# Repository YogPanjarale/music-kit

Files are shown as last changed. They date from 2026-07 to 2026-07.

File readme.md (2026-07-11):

# Touch Music Kit

Touch Music Kit is an ESP32-based music controller PCB with seven capacitive touch pads, a small OLED display, physical controls, addressable LED output, and a PAM8403 audio amplifier module interface.

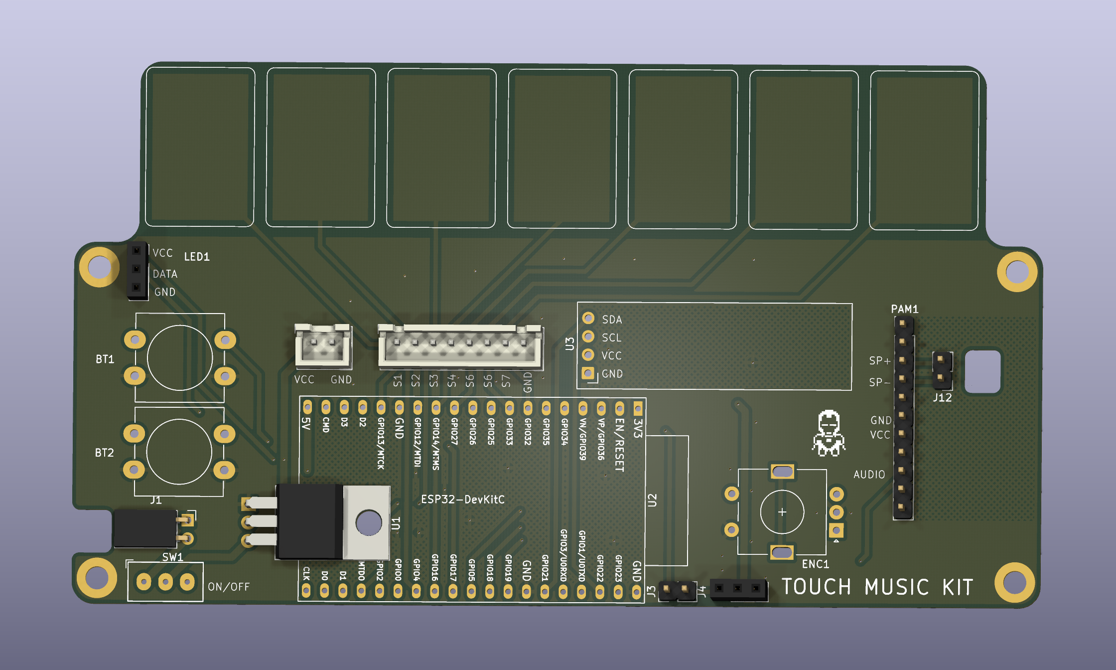
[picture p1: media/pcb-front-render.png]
PCB front render


## Features

- ESP32-DevKitC module as the main controller.
- Seven on-board capacitive touch pads labeled `S1` through `S7`.
- 0.91 inch SSD1306 I2C OLED module.
- Rotary encoder with integrated push switch.
- Two 12 mm push buttons.
- Slide power switch and power input connectors.
- PAM8403 amplifier module header for audio output.
- Speaker output intended for a 0.5 W, 8 ohm, 32 mm speaker through the PAM8403 module.
- NeoPixel-compatible 3-pin LED header.
- LM1117T-3.3 regulator footprint.
- KiCad project files plus fabrication outputs for board manufacturing.

## Repository Layout

```text
.
|-- hardware/
|   `-- touch-kit/
|       |-- music-kit.kicad_pro
|       |-- music-kit.kicad_sch
|       |-- music-kit.kicad_pcb
|       `-- *_production/
|           `-- dated export folder/
|               |-- Gerber ZIP
|               |-- BOM CSV
|               |-- position CSV
|               `-- IPC netlist
|-- media/
|   `-- pcb-front-render.png
`-- software/
```

The `software/` directory is currently empty.

## Hardware Overview

| Designator | Part / Module | Notes |
| --- | --- | --- |
| `U2` | ESP32-DevKitC | Main controller module. |
| `U3` | ER_OLEDM0.91_1x-I2C | 0.91 inch, 128x32, SSD1306 I2C OLED. |
| `ENC1` | EC11-style rotary encoder | Encoder with push switch. |
| `BT1`, `BT2` | 12 mm push buttons | User input buttons. |
| `J5` | JST-XH 1x08 input connector | Breaks out `S1` through `S7` plus `GND`. |
| `LED1` | 3-pin NeoPixel header | `VCC`, `DATA`, `GND`. |
| `PAM1` | PAM8403 module header | 1x11 header with audio output, DAC input, power, and ground nets. |
| `J4` | 3-pin DAC/audio header | `DAC_OUT`, `VCC`, and `GND`; schematic value is `Speakerdf`. |
| `J1`, `J6` | Power connectors | Auxiliary power and JST-XH power input. |
| `SW1` | Slide switch | Board on/off switch. |
| `U1` | LM1117T-3.3 | 3.3 V regulator footprint. |

The board outline is approximately 134 mm x 75 mm, based on the KiCad edge cuts and dimension markings.

## Firmware Pin Map

This map is derived from the KiCad PCB nets connected to `U2` (`ESP32-DevKitC`).

| Signal | ESP32 GPIO | Purpose |
| --- | ---: | --- |
| `S1` | GPIO4 | Capacitive touch input |
| `S2` | GPIO15 | Capacitive touch input |
| `S3` | GPIO13 | Capacitive touch input |
| `S4` | GPIO14 | Capacitive touch input |
| `S5` | GPIO27 | Capacitive touch input |
| `S6` | GPIO33 | Capacitive touch input |
| `S7` | GPIO32 | Capacitive touch input |
| `DAC_MCU` | GPIO25 | ESP32 DAC/audio signal |
| `WS_DATA` | GPIO26 | NeoPixel data |
| `BT1` | GPIO16 | Push button 1 |
| `BT2` | GPIO17 | Push button 2 |
| `ENC_SW` | GPIO5 | Encoder switch |
| `ENC_DT` | GPIO18 | Encoder data |
| `ENC_CLK` | GPIO19 | Encoder clock |
| `SDA` | GPIO21 | OLED I2C data |
| `SCL` | GPIO22 | OLED I2C clock |

Note: the current PCB silkscreen labels the fifth and sixth input positions as `S6`, `S6`. The KiCad nets show those positions as `S5` and `S6`, so verify the board file before ordering or assembling.

## Manufacturing Files

Open the KiCad project from:

```text
hardware/touch-kit/music-kit.kicad_pro
```

Ready-to-send fabrication outputs are under the production export folder in `hardware/touch-kit/`. The current export can be found with:

```text
hardware/touch-kit/*_production/2026-07-02-17-41-01/
```

That folder includes the Gerber ZIP, BOM CSV, position CSV, and IPC netlist generated from the KiCad PCB. If you change the schematic or PCB, regenerate the manufacturing files from KiCad before ordering.

## Assembly Notes

- Confirm `VCC`, `+BATT`, and `GND` with a multimeter before plugging in the ESP32, OLED, or amplifier module.
- Install the ESP32-DevKitC, OLED, PAM8403 module, buttons, encoder, headers, and power connectors according to the silkscreen and BOM.
- Use the PAM8403 module with the knob-style amplifier header expected by `PAM1`.
- Connect the speaker through the PAM8403 module output pins marked `SP+` and `SP-`; do not assume `J4` is the raw speaker output without checking the board file.
- The NeoPixel header `LED1` is labeled `VCC`, `DATA`, `GND`; data is driven by `WS_DATA` / GPIO26.

## Firmware Status

Firmware is not included yet. A firmware project should initialize:

- ESP32 capacitive touch readings for `S1` through `S7`.
- SSD1306 display over I2C on GPIO21/GPIO22.
- Audio or DAC output on GPIO25.
- NeoPixel output on GPIO26.
- Button and encoder inputs on GPIO16, GPIO17, GPIO5, GPIO18, and GPIO19.

## License

This project is licensed under the MIT License. See [LICENSE](LICENSE).

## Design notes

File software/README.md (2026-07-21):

# Touch Music Kit — Firmware

ESP32-DevKitC firmware for the Touch Music Kit PCB. A menu-driven polyphonic
synth: seven pads trigger notes, a rotary encoder drives an OLED menu, and audio
renders to the on-chip DAC (GPIO25) into the PAM8403 amplifier and speaker.

## Build & Flash

Requires [PlatformIO Core](https://platformio.org/install) (`pio`).

```bash
pio run                 # compile
pio run -t upload       # compile + flash over USB
pio device monitor      # serial console @ 115200 baud
pio run -t upload -t monitor   # flash then open the monitor
```

The first `pio run` downloads the ESP32 platform and the three Adafruit
libraries (GFX, SSD1306, NeoPixel), pinned in `platformio.ini`.

## Controls

| Control | GPIO | Action |
| --- | ---: | --- |
| Rotary encoder — rotate | CLK 18 / DT 19 | Move between menu items, or edit the selected value |
| Rotary encoder — press | SW 5 | Toggle **SEL** ⇄ **EDIT** (rotate then edits the value) |
| Button 1 (DOWN) | 16 | Previous scale (jumps the menu to Scale) |
| Button 2 (UP) | 17 | Next scale |
| Pads S1–S7 | see pin map | Play notes in the selected input mode |

Encoder feels backwards? Flip `ENCODER_REVERSE` in `src/main.cpp`.

## Menu

Four items, shown on the 128×32 OLED as `SEL/EDIT  n/4  Label`:

### 1. Input — how a pad triggers a note
- **Capacitive** *(default)* — ESP32 `touchRead()` on the seven pads. This is
  the normal mode for the touch PCB.
- **Digital** — the same seven GPIOs read as active-HIGH digital inputs, for
  comparator / LDR / laser-harp / switch outputs wired into the pad connector.

### 2. Voice — how a note sounds (all rendered to the DAC)
| Voice | Character | Behaviour |
| --- | --- | --- |
| **String** | Plucked, warm | Karplus-Strong; rings out and decays (one-shot) |
| **Piano** | Bright pluck | Shorter pluck + an octave harmonic (one-shot) |
| **Keyboard** | Sustained organ-ish | Sounds while the pad is **held**, releases when let go |
| **Percussion** | Drum hit | Noise burst + pitch-dropping body (one-shot) |
| **Flute** | Breathy, gentle vibrato | Near-pure tone + breath noise; sustains while **held** |

> **Keyboard** and **Flute** sustain while held; the others trigger and decay on
> their own. Note-off is tracked per pad, so releasing a held note fades it out
> cleanly.

### 3. Scale — 7 semitone offsets mapped to the pads
14 scales (Major, Dorian, … Hirajoshi). The two buttons also change this
directly. Root note is C4 (`ROOT` in `src/main.cpp`).

### 4. Screen — OLED orientation
Toggles the OLED between **Normal** and **Flipped** (rotated 180°) so the menu
is readable from the opposite side of the board. Any encoder turn while editing
flips it. Display-only — the LED strip and pad order are not mirrored.

## Sound Reference

### Voices — how each is synthesised

All voices are generated on-chip and played out the DAC; there is no sample
memory. Each pad = one note of the current scale.

| Voice | Technique | Character & tips |
| --- | --- | --- |
| **String** | Karplus-Strong: a burst of noise cycled through a short delay line that low-pass filters itself each pass, so it starts bright and mellows as it rings. | Warm plucked-string / harp. Long natural decay (~3 s). Best with pentatonic/blues scales for a harp feel. |
| **Piano** | Same pluck, but shorter and less smoothed, plus an octave-up copy layered on top. | Brighter, more percussive attack, shorter tail. Good for melodic lines and chords. |
| **Keyboard** | Additive oscillator: fundamental + octave + fifth-above sines summed, shaped by an attack/release envelope. | Sustained organ-ish tone that **holds while a pad is held**. Fuller, more "electric organ" than the plucks. |
| **Percussion** | A short pitched sine "body" whose pitch drops instantly, mixed with a fast-decaying noise burst. | Drum/tom-like hits. Lower pads sound like toms/kick, higher pads snappier. Scale mostly changes the pitch of the thump. |
| **Flute** | Near-pure sine (fundamental + a faint octave) plus a little breath noise, with a gentle ~5 Hz vibrato, attack/release envelope. | Soft, airy, **sustains while held**. Slow attack makes fast passages blur — good for slow melodies. |

Plucks (String, Piano) and Percussion are *one-shot*: they trigger and ring out
on their own. Keyboard and Flute are *sustained*: they keep sounding until you
release the pad. Up to 10 notes can sound at once (`MAX_VOICES`).

### Scales — the mood of each

A scale is just seven semitone offsets from the root (C4) mapped to pads S1→S7,
low to high. Switch scales with the encoder (Scale item) or the two buttons.
Rough character of each:

**Common modes**
- **Major (Ionian)** — the standard "happy"/bright do-re-mi scale.
- **Natural Minor (Aeolian)** — the standard "sad"/serious minor scale.
- **Dorian** — minor but hopeful; jazzy, Celtic, folk flavour.
- **Phrygian** — dark minor with a lowered 2nd; Spanish/flamenco, metal edge.
- **Lydian** — major with a raised 4th; dreamy, floating, "film score" wonder.
- **Mixolydian** — major with a lowered 7th; bluesy, rock, dominant feel.
- **Locrian** — the darkest, most unstable mode; tense and dissonant.

**Colourful / exotic**
- **Harmonic Minor** — minor with a raised 7th; dramatic, classical, Middle-Eastern.
- **Phrygian Dominant** — Spanish/Arabic sound; the "flamenco" scale.
- **Hirajoshi** — a Japanese pentatonic scale; sparse, meditative, koto-like.
- **Whole Tone** — every step a whole tone apart; dreamlike, ambiguous, "no home".

**Easy / forgiving (great for improvising — no wrong notes)**
- **Major Pentatonic** — five bright notes; cheerful, folky, hard to sound bad.
- **Minor Pentatonic** — five moody notes; the backbone of rock/blues solos.
- **Blues** — minor pentatonic plus the "blue note"; soulful, gritty.

If you just want to noodle and have it always sound musical, pick one of the
pentatonic scales or Blues.

## Pin Map

Matches the PCB net map (`../readme.md`).

| Signal | GPIO | Notes |
| --- | ---: | --- |
| Pad S1 | 4 | touch T0 |
| Pad S2 | 15 | touch T3 |
| Pad S3 | 13 | touch T4 |
| Pad S4 | 14 | touch T6 |
| Pad S5 | 27 | touch T7 |
| Pad S6 | 33 | touch T8 |
| Pad S7 | 32 | touch T9 |
| DAC audio out | 25 | → PAM8403 → speaker |
| NeoPixel data | 26 | `WS_DATA`, one LED per pad |
| Button 1 / 2 | 16 / 17 | active-LOW, internal pull-ups |
| Encoder SW / CLK / DT | 5 / 18 / 19 | active-LOW switch, pull-ups |
| OLED SDA / SCL | 21 / 22 | SSD1306 @ I2C 0x3C |

## Tuning

Everything is `const` at the top of `src/main.cpp`:

- **Touch sensitivity** — `TOUCH_ON` / `TOUCH_OFF` (hysteresis; lower = touched).
  Check the "resting touch levels" line printed at boot and set `TOUCH_ON` well
  below the resting value.
- **Digital input polarity** — `DIGITAL_INPUT_ACTIVE_LOW`, `DIGITAL_INPUT_PULLDOWNS`.
- **Retrigger rate** — `COOLDOWN_MS` (min gap between triggers on one pad).
- **Voice character** — the `INSTRUMENTS[]` table: pluck `decay`/`smoothPasses`/
  `lifeSec`, Keyboard/Flute `attackSec`/`releaseSec`, Percussion `percDecaySec`.
  The Keyboard and Flute harmonic/breath mix lives in `renderSample()`
  (`VK_TONE` / `VK_FLUTE` branches); flute vibrato is `VIB_RATE`/`VIB_DEPTH`.
- **Polyphony / audio** — `MAX_VOICES`, `SR` (sample rate), `LED_BRIGHTNESS`.

Serial (115200) prints every trigger with pad, frequency, and (in Capacitive
mode) the raw touch value — useful for calibrating `TOUCH_ON`/`TOUCH_OFF`.

## Layout

```
software/
├── platformio.ini   # esp32dev / Arduino env + pinned libs
├── src/main.cpp      # firmware
├── old.cpp           # previous single-mode sketch, kept for reference (not built)
└── README.md
```

`old.cpp` sits outside `src/`, so PlatformIO does not compile it.

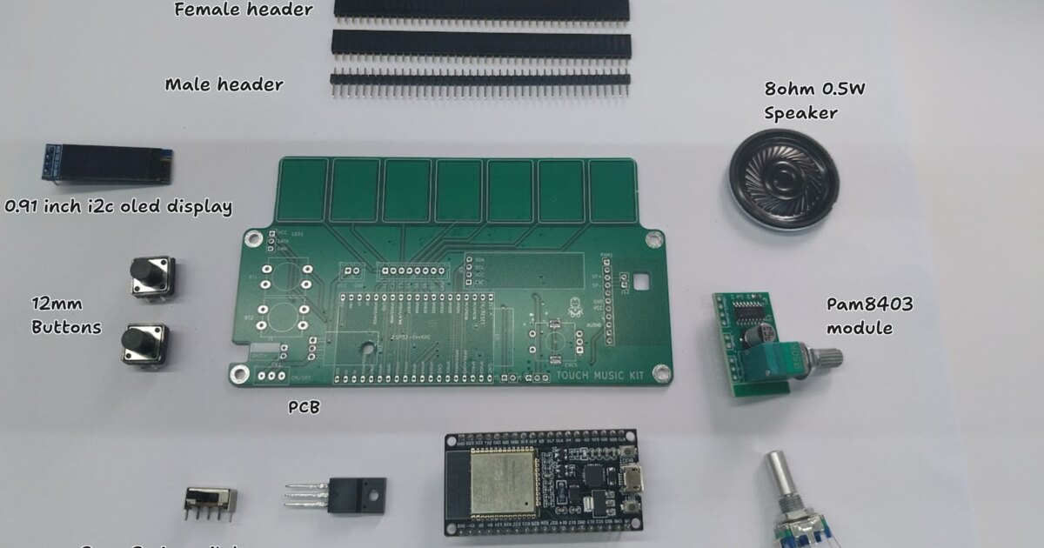
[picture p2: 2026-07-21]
docs/cover.jpg

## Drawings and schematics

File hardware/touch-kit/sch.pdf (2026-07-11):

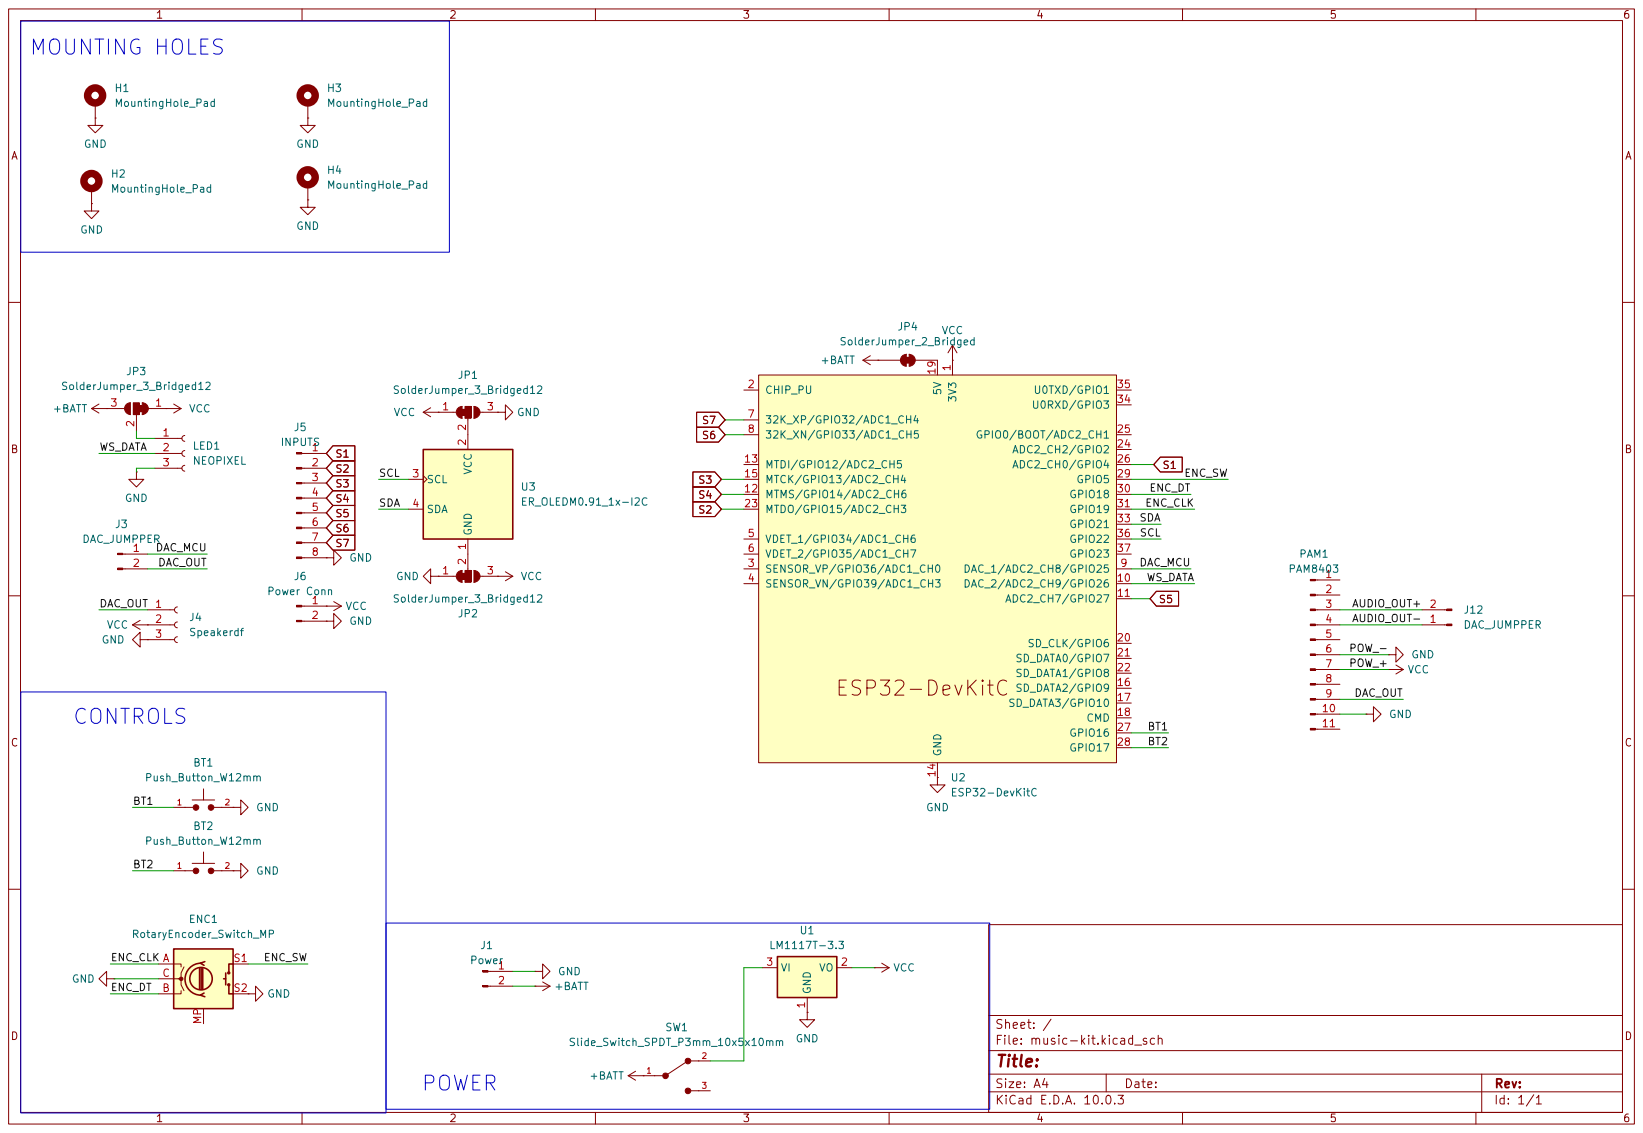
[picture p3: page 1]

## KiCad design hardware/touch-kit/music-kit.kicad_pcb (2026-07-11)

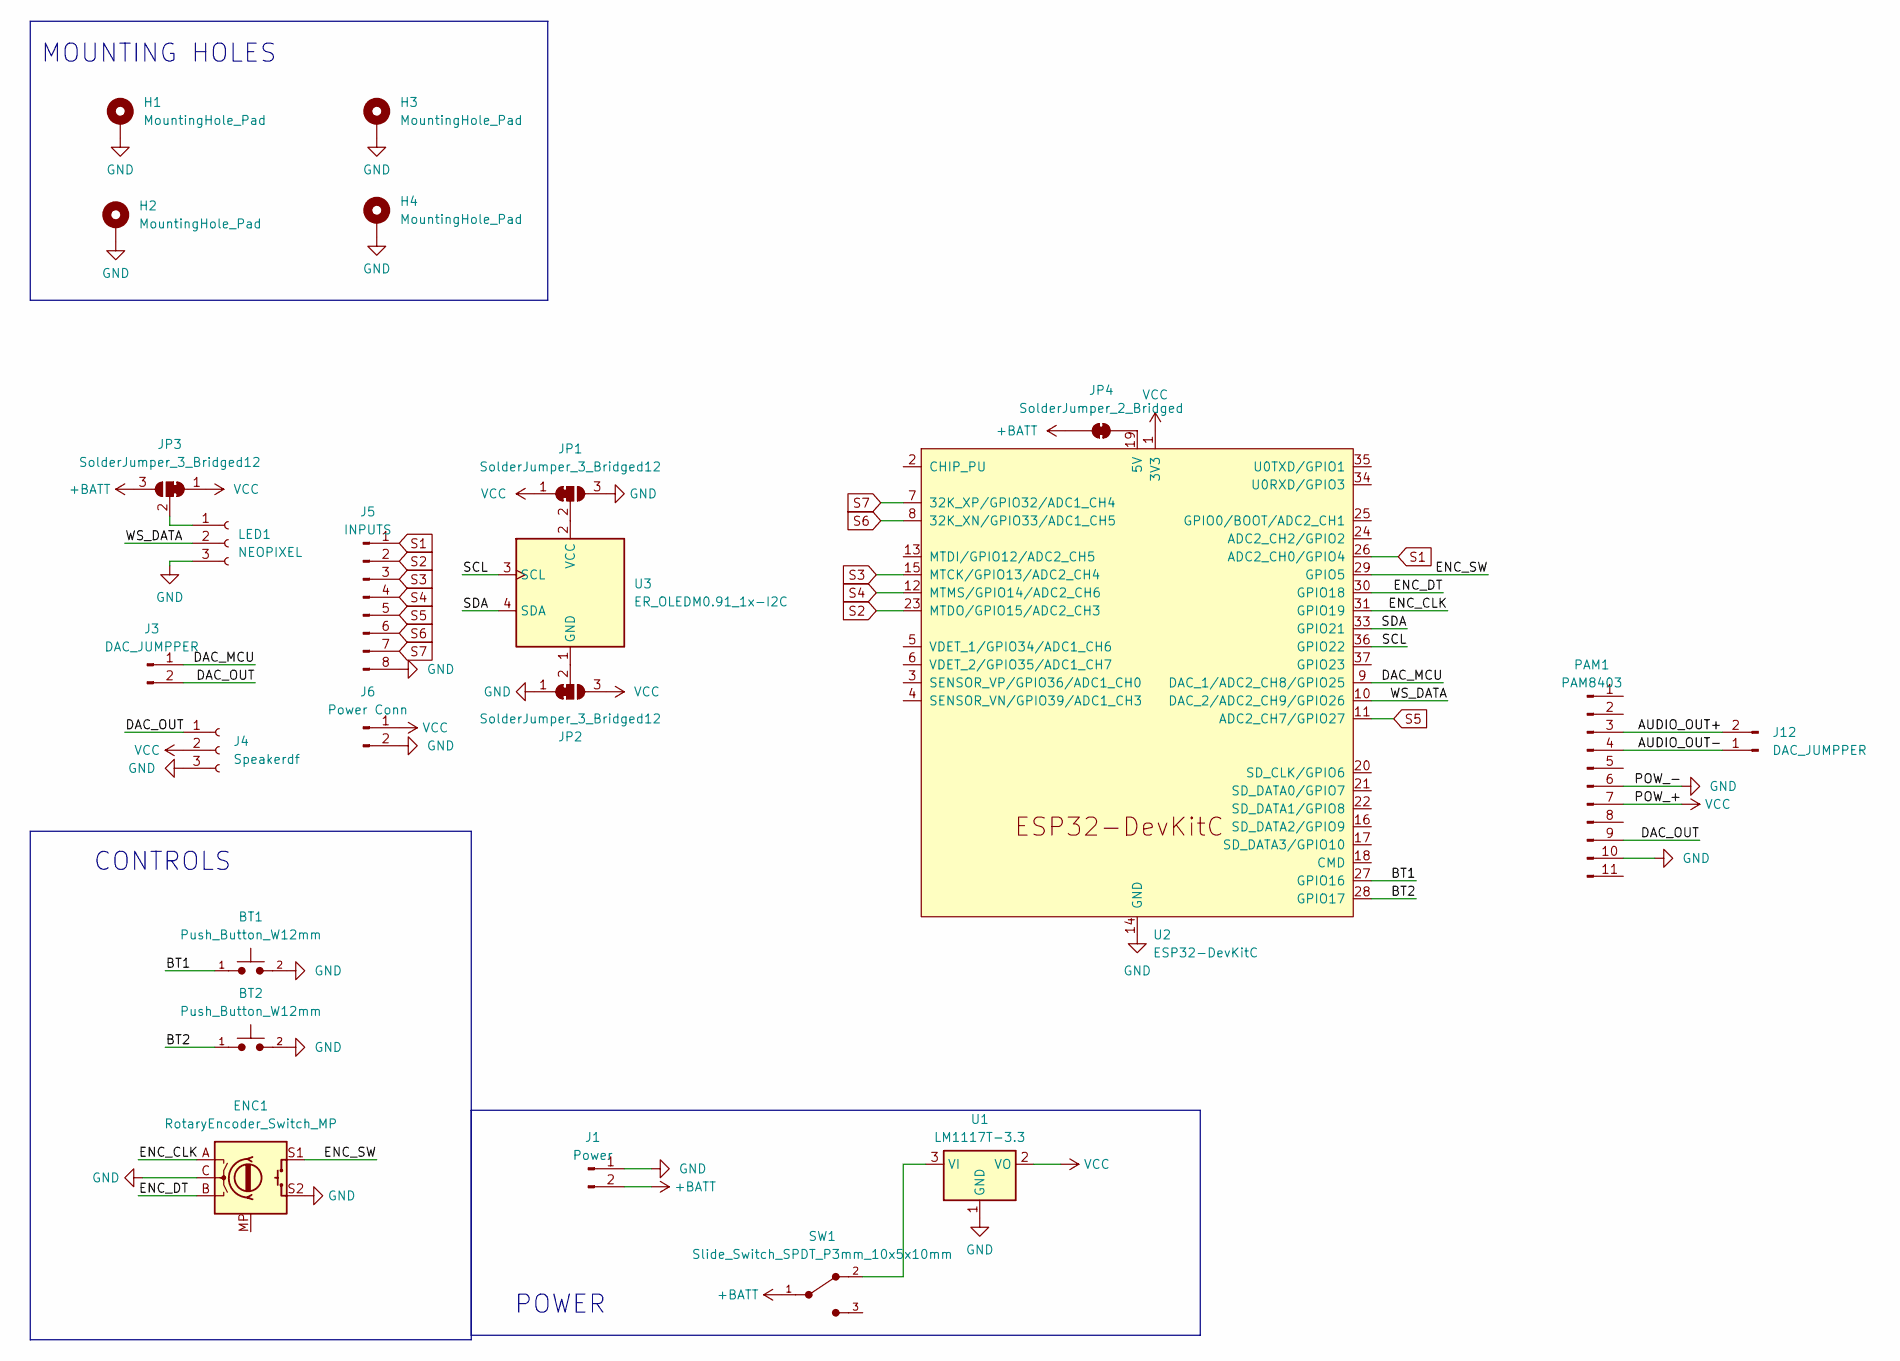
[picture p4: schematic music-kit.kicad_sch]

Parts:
BT1, BT2: Push_Button_W12mm
ENC1: RotaryEncoder_Switch_MP; RotaryEncoder_Alps_EC11E-Switch_Vertical_H20mm
H1, H2, H3, H4: MountingHole_Pad; MountingHole_3.2mm_M3_DIN965_Pad
J1: Power; PinSocket_1x02_P2.54mm_Horizontal
J3, J12: DAC_JUMPPER; PinHeader_1x02_P2.54mm_Vertical
J4: Speakerdf; PinSocket_1x03_P2.54mm_Vertical
J5: INPUTS; JST_XH_B8B-XH-A_1x08_P2.50mm_Vertical
J6: Power Conn; JST_XH_B2B-XH-A_1x02_P2.50mm_Vertical
JP1, JP2, JP3: SolderJumper_3_Bridged12; SolderJumper-3_P1.3mm_Bridged12_Pad1.0x1.5mm
JP4: SolderJumper_2_Bridged; SolderJumper-2_P1.3mm_Bridged_Pad1.0x1.5mm
LED1: NEOPIXEL; PinSocket_1x03_P2.54mm_Vertical
PAM1: PAM8403; PinHeader_1x11_P2.54mm_Vertical
SW1: Slide_Switch_SPDT_P3mm_10x5x10mm
U1: LM1117T-3.3; TO-220-3_Horizontal_TabDown
U2: ESP32-DevKitC
U3: ER_OLEDM0.91_1x-I2C

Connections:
+BATT: J1.2, JP3.3 (B), JP4.1 (A), SW1.1
/AUDIO_OUT+: J12.2, PAM1.3
/AUDIO_OUT-: J12.1, PAM1.4
/BT1: BT1.1, U2.27 (GPIO16)
/BT2: BT2.1, U2.28 (GPIO17)
/DAC_MCU: J3.1, U2.9 (DAC_1/ADC2_CH8/GPIO25)
/DAC_OUT: J3.2, J4.1, PAM1.9
/ENC_CLK: ENC1.A, U2.31 (GPIO19)
/ENC_DT: ENC1.B, U2.30 (GPIO18)
/ENC_SW: ENC1.S1, U2.29 (GPIO5)
/SCL: U2.36 (GPIO22), U3.3 (SCL)
/SDA: U2.33 (GPIO21), U3.4 (SDA)
/WS_DATA: LED1.2, U2.10 (DAC_2/ADC2_CH9/GPIO26)
GND: BT1.2, BT2.2, ENC1.C, ENC1.S2, H1.1 (1_1), H2.1 (1_1), H3.1 (1_1), H4.1 (1_1), J1.1, J4.3, J5.8, J6.2, JP1.3 (B), JP2.1 (A), LED1.3, PAM1.6, PAM1.10, U1.1 (GND), U2.14 (GND), U2.32 (GND), U2.38 (GND)
unnamed: JP1.2 (C), U3.2 (VCC)
unnamed: JP2.2 (C), U3.1 (GND)
unnamed: JP3.2 (C), LED1.1
unnamed: JP4.2 (B), U2.19 (5V)
unnamed: SW1.2, U1.3 (VI)
S1: J5.1, U2.26 (ADC2_CH0/GPIO4)
S2: J5.2, U2.23 (MTDO/GPIO15/ADC2_CH3)
S3: J5.3, U2.15 (MTCK/GPIO13/ADC2_CH4)
S4: J5.4, U2.12 (MTMS/GPIO14/ADC2_CH6)
S5: J5.5, U2.11 (ADC2_CH7/GPIO27)
S6: J5.6, U2.8 (32K_XN/GPIO33/ADC1_CH5)
S7: J5.7, U2.7 (32K_XP/GPIO32/ADC1_CH4)
VCC: J4.2, J6.1, JP1.1 (A), JP2.3 (B), JP3.1 (A), PAM1.7, U1.2 (VO), U2.1 (3V3)

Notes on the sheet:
POWER
CONTROLS
MOUNTING HOLES

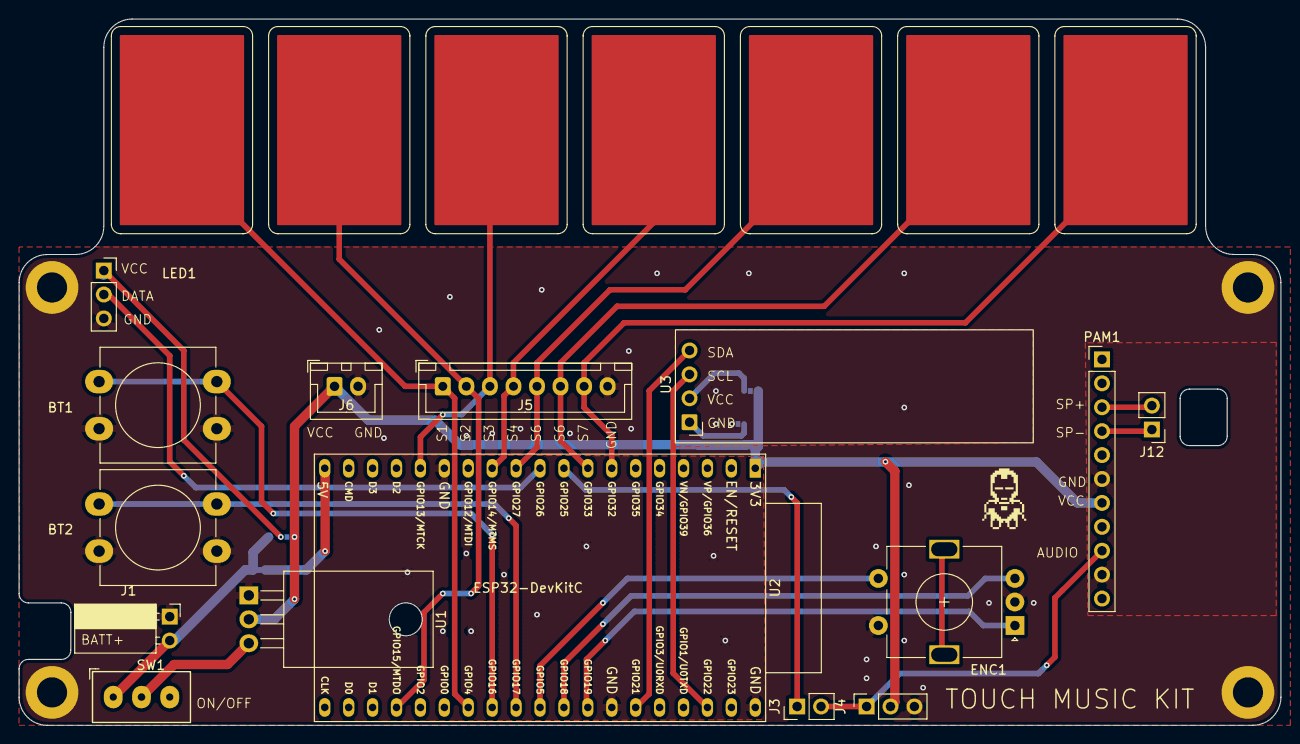
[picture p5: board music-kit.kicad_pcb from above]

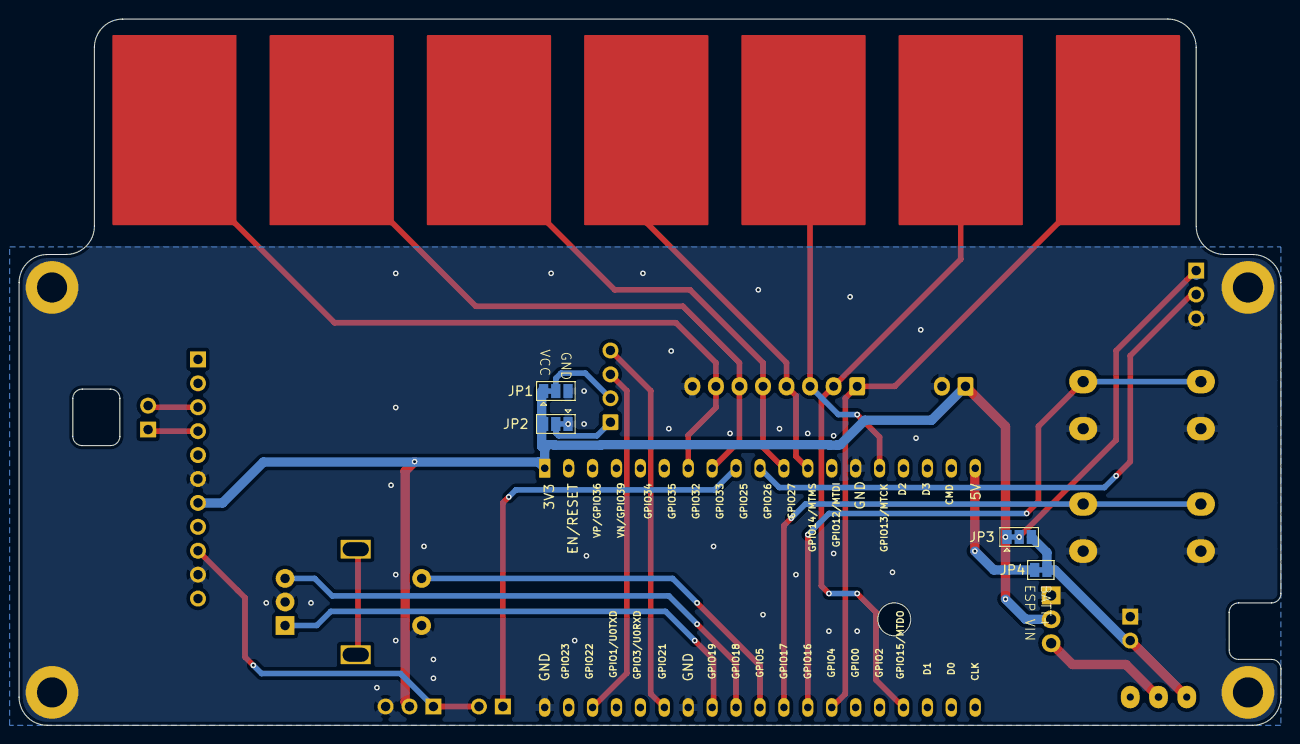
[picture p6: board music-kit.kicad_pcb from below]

Board: 2 copper layers, 134.0 x 75.0 mm, 23 parts (4 on the bottom side), 27 nets.

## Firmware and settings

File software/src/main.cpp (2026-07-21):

/*
 * Touch Music Kit  ->  Menu-driven synth
 * ------------------------------------------------------------
 * INPUT MODES (how a pad triggers a note):
 *   - Capacitive : ESP32 touchRead() on the 7 pads (default; matches the PCB).
 *   - Digital    : same 7 GPIOs read as active-HIGH digital inputs
 *                  (comparator / LDR / laser-harp / switch outputs).
 *
 * INSTRUMENT TYPES (how a note sounds, all rendered to the DAC):
 *   - String     : plucked Karplus-Strong, rings out and decays.
 *   - Piano      : short, bright plucked variant with an octave harmonic.
 *   - Keyboard   : sustained organ-ish tone; holds while the pad is held,
 *                  releases when let go (only Capacitive/Digital press-hold).
 *   - Percussion : drum-style noise+pitch hit, one-shot.
 *
 * Rotary encoder menu:  GPIO5 = SW   GPIO18 = CLK   GPIO19 = DT
 * Scale buttons:        GPIO16 = DOWN (prev)   GPIO17 = UP (next)
 *   Wire each button between the pin and GND (internal pull-ups are used).
 *
 * Audio renders in small chunks in loop() between scans, so notes ring out
 * continuously without blocking input.
 *
 * Board: ESP32-DevKitC. DAC = GPIO25 -> PAM8403 -> speaker. Serial @ 115200.
 */

#include <Arduino.h>
#include <Wire.h>
#include <Adafruit_GFX.h>
#include <Adafruit_SSD1306.h>
#include <Adafruit_NeoPixel.h>
#include <math.h>
#include <string.h>

// ============================================================
//  CONFIG
// ============================================================
const int DAC_PIN = 25;

const int NUM = 7;
// Pad order follows the PCB net map S1..S7 (see readme "Firmware Pin Map").
const uint8_t PAD_PIN[NUM] = {
    4,   // S1: GPIO4  / touch T0
    15,  // S2: GPIO15 / touch T3
    13,  // S3: GPIO13 / touch T4
    14,  // S4: GPIO14 / touch T6
    27,  // S5: GPIO27 / touch T7
    33,  // S6: GPIO33 / touch T8
    32   // S7: GPIO32 / touch T9
};

// Capacitive touch detection with hysteresis: touchRead returns LOWER when touched.
const int TOUCH_ON   = 30;   // below this = touched
const int TOUCH_OFF  = 45;   // above this = released
const uint32_t COOLDOWN_MS = 120;   // min time between triggers on the same pad

// Digital input mode: same 7 GPIOs, active-HIGH by default.
const bool DIGITAL_INPUT_PULLDOWNS  = true;
const bool DIGITAL_INPUT_ACTIVE_LOW = false;
uint8_t    lastDigitalActiveMask    = 0xFF; // force one raw GPIO status print at boot

enum PlayMode {
  MODE_CAPACITIVE = 0,   // ESP32 touchRead pads
  MODE_DIGITAL,          // active-HIGH GPIO inputs (comparator / LDR / switch)
  PLAY_MODE_COUNT
};
PlayMode playMode = MODE_CAPACITIVE;

// Scale-select buttons (active LOW, internal pull-up)
const int BTN_PIN[2] = { 16, 17 };   // [0] = DOWN/prev, [1] = UP/next

// Rotary encoder (active LOW switch, internal pull-ups)
const int ENC_SW_PIN  = 5;
const int ENC_CLK_PIN = 18;
const int ENC_DT_PIN  = 19;
const bool ENCODER_REVERSE = false;  // flip if clockwise feels backwards

// 0.91" OLED (SSD1306, 128x32) on I2C: SDA=21, SCL=22, address 0x3C
const int OLED_SDA  = 21;
const int OLED_SCL  = 22;
const int OLED_ADDR = 0x3C;
Adafruit_SSD1306 display(128, 32, &Wire, -1);
bool oledOK = false;

// NeoPixel pin-activity display: one RGB LED per pad on GPIO26 (PCB WS_DATA net).
// LED index matches pad index; active pads stay lit, triggers flash briefly.
const int LED_PIN   = 26;
const int LED_COUNT = NUM;
Adafruit_NeoPixel strip(LED_COUNT, LED_PIN, NEO_GRB + NEO_KHZ800);
const uint8_t LED_BRIGHTNESS = 70; // global cap (keeps current draw sane)
const uint8_t CAP_ACTIVE_RGB[3] = {   0, 220, 255 }; // capacitive touch active
const uint8_t DIG_ACTIVE_RGB[3] = { 255,  40,   0 }; // digital GPIO active

// LED signal state: active pads stay lit, fresh triggers fade from white.
float    ledLevel[NUM] = { 0 };
bool     ledsDirty     = true;     // forces one redraw after state changes
uint32_t lastFrame     = 0;
const uint32_t FRAME_MS = 33;      // ~30fps, only redraws on changes/flash decay

// ============================================================
//  SCALES  (root + 7 semitone offsets)
// ============================================================
const float ROOT = 261.63f;          // C4 -- change to transpose everything

// 7 semitone steps per scale, relative to ROOT.
// Add a row here and matching names below -- NUM_SCALES updates itself.
const int SCALE_STEPS[][NUM] = {
  {  0,  2,  4,  5,  7,  9, 11 },   // Major (Ionian)
  {  0,  2,  3,  5,  7,  9, 10 },   // Dorian
  {  0,  1,  3,  5,  7,  8, 10 },   // Phrygian
  {  0,  2,  4,  6,  7,  9, 11 },   // Lydian
  {  0,  2,  4,  5,  7,  9, 10 },   // Mixolydian
  {  0,  2,  3,  5,  7,  8, 10 },   // Natural Minor (Aeolian)
  {  0,  1,  3,  5,  6,  8, 10 },   // Locrian
  {  0,  2,  3,  5,  7,  8, 11 },   // Harmonic Minor
  {  0,  2,  4,  7,  9, 12, 14 },   // Major Pentatonic (runs into next octave)
  {  0,  3,  5,  7, 10, 12, 15 },   // Minor Pentatonic (runs into next octave)
  {  0,  3,  5,  6,  7, 10, 12 },   // Blues
  {  0,  2,  4,  6,  8, 10, 12 },   // Whole Tone
  {  0,  1,  4,  5,  7,  8, 10 },   // Phrygian Dominant (Spanish/Arabic)
  {  0,  2,  3,  7,  8, 12, 14 },   // Hirajoshi (Japanese)
};
const char* SCALE_NAME[] = {
  "Major", "Dorian", "Phrygian", "Lydian", "Mixolydian", "Natural Minor",
  "Locrian", "Harmonic Minor", "Major Pentatonic", "Minor Pentatonic",
  "Blues", "Whole Tone", "Phrygian Dominant", "Hirajoshi"
};
const char* SCALE_SHORT_NAME[] = {
  "Major", "Dorian", "Phryg", "Lydian", "Mixolyd", "NatMin",
  "Locrian", "HarmMin", "MajPent", "MinPent", "Blues", "Whole",
  "PhrDom", "Hirajo"
};
const int NUM_SCALES = sizeof(SCALE_STEPS) / sizeof(SCALE_STEPS[0]);

// ============================================================
//  INSTRUMENTS  (voice families)
// ============================================================
enum VoiceKind {
  VK_PLUCK,   // Karplus-Strong pluck (self-decaying)
  VK_TONE,    // sustained additive oscillator with attack/release envelope
  VK_PERC,    // percussive noise + pitched body, one-shot
  VK_FLUTE    // sustained breathy near-sine tone with gentle vibrato
};

// Sustained voices hold while the pad is held and fade on release.
inline bool isSustainedKind(VoiceKind k) { return k == VK_TONE || k == VK_FLUTE; }

struct Instrument {
  const char* name;
  const char* detail;
  VoiceKind   kind;
  // --- pluck params ---
  float decay;
  int   smoothPasses;
  float lifeSec;
  bool  harmonic;      // add an octave-up pluck
  // --- tone params ---
  float attackSec;
  float releaseSec;
  // --- perc params ---
  float percDecaySec;
};

const Instrument INSTRUMENTS[] = {
  // name          detail          kind      decay    sm  life   harm    atk     rel    perc
  { "String",     "Plucked",      VK_PLUCK, 0.9968f, 5,  3.2f,  false,  0.0f,   0.0f,  0.0f  },
  { "Piano",      "Bright pluck", VK_PLUCK, 0.9928f, 1,  1.4f,  true,   0.0f,   0.0f,  0.0f  },
  { "Keyboard",   "Sustained",    VK_TONE,  0.0f,    0,  0.0f,  false,  0.006f, 0.18f, 0.0f  },
  { "Percussion", "Drum hits",    VK_PERC,  0.0f,    0,  0.0f,  false,  0.0f,   0.0f,  0.32f },
  { "Flute",      "Breathy",      VK_FLUTE, 0.0f,    0,  0.0f,  false,  0.040f, 0.12f, 0.0f  },
};
const int NUM_INSTRUMENTS = sizeof(INSTRUMENTS) / sizeof(INSTRUMENTS[0]);

int   scaleIdx      = 0;
int   instrumentIdx = 0;
float noteFreq[NUM];                 // current pad frequencies (built from scale)

enum MenuItem {
  MENU_MODE = 0,
  MENU_INSTRUMENT,
  MENU_SCALE,
  MENU_SCREEN,
  MENU_COUNT
};

int  menuIdx     = MENU_MODE;
bool menuEditing = false;
bool screenFlipped = false;   // true = OLED rotated 180 for viewing from the far side
const char* scaleButtonMsg = "";
uint32_t scaleButtonMsgUntil = 0;

// ---- forward declarations ----
void drawMenu();
void configurePadInputs();
void resetPadStates();
void startPluck(float freq, float decay, int smoothPasses, float lifeSec);

int wrapIndex(int value, int count) {
  while (value < 0) value += count;
  while (value >= count) value -= count;
  return value;
}

void pulseAllLeds(float level = 220.0f) {
  for (int i = 0; i < NUM; i++) ledLevel[i] = level;
  ledsDirty = true;
}

void applyScale() {
  for (int i = 0; i < NUM; i++) {
    noteFreq[i] = ROOT * powf(2.0f, SCALE_STEPS[scaleIdx][i] / 12.0f);
  }
  Serial.printf("scale -> %s\n", SCALE_NAME[scaleIdx]);
  pulseAllLeds();
  drawMenu();
}

void changeScale(int delta) {
  if (delta == 0) return;
  scaleIdx = wrapIndex(scaleIdx + delta, NUM_SCALES);
  applyScale();
}

void changeInstrument(int delta) {
  if (delta == 0) return;
  instrumentIdx = wrapIndex(instrumentIdx + delta, NUM_INSTRUMENTS);
  Serial.printf("voice -> %s\n", INSTRUMENTS[instrumentIdx].name);
  pulseAllLeds();
  drawMenu();
}

const char* playModeName() {
  return playMode == MODE_CAPACITIVE ? "Capacitive" : "Digital";
}

void setPlayMode(PlayMode mode) {
  if (playMode == mode) return;
  playMode = mode;
  configurePadInputs();
  resetPadStates();
  Serial.printf("mode -> %s\n", playModeName());
  drawMenu();
}

void changePlayMode(int delta) {
  if (delta == 0) return;
  setPlayMode((PlayMode)wrapIndex((int)playMode + delta, PLAY_MODE_COUNT));
}

void applyScreenRotation() {
  if (!oledOK) return;
  display.setRotation(screenFlipped ? 2 : 0);   // SSD1306: 2 = 180 degrees
}

void toggleScreenFlip() {
  screenFlipped = !screenFlipped;
  applyScreenRotation();
  Serial.printf("screen -> %s\n", screenFlipped ? "flipped 180" : "normal");
  drawMenu();
}

// ============================================================
//  OLED MENU
// ============================================================
const int OLED_W = 128;
const int OLED_CHAR_COLS = 21;       // 128px / 6px font width at text size 1

void printClipped(const char* text, int maxChars = OLED_CHAR_COLS) {
  for (int i = 0; i < maxChars && text[i] != '\0'; i++) {
    display.write(text[i]);
  }
}

const char* menuLabel() {
  switch (menuIdx) {
    case MENU_MODE:       return "Input";
    case MENU_INSTRUMENT: return "Voice";
    case MENU_SCALE:      return "Scale";
    case MENU_SCREEN:     return "Screen";
    default:              return "Menu";
  }
}

const char* menuValue() {
  switch (menuIdx) {
    case MENU_MODE:       return playModeName();
    case MENU_INSTRUMENT: return INSTRUMENTS[instrumentIdx].name;
    case MENU_SCALE:      return SCALE_SHORT_NAME[scaleIdx];
    case MENU_SCREEN:     return screenFlipped ? "Flipped" : "Normal";
    default:              return "";
  }
}

const char* menuDetail() {
  switch (menuIdx) {
    case MENU_MODE:
      return playMode == MODE_CAPACITIVE ? "Touch pads" : "GPIO inputs";
    case MENU_INSTRUMENT:
      return INSTRUMENTS[instrumentIdx].detail;
    case MENU_SCALE:
      return scaleButtonMsgUntil ? scaleButtonMsg : SCALE_NAME[scaleIdx];
    case MENU_SCREEN:
      return screenFlipped ? "180 view" : "Upright";
    default:
      return "";
  }
}

void drawCenteredText(const char* text, int y, uint8_t size) {
  int16_t x1, y1;
  uint16_t w, h;
  display.setTextSize(size);
  display.getTextBounds(text, 0, y, &x1, &y1, &w, &h);
  int x = (OLED_W - (int)w) / 2 - x1;
  if (x < 0) x = 0;
  display.setCursor(x, y);
  display.print(text);
}

void drawMenuHeader() {
  char header[24];
  snprintf(header, sizeof(header), "%s %d/%d %s", menuEditing ? "EDIT" : "SEL", menuIdx + 1, MENU_COUNT, menuLabel());

  display.setTextSize(1);
  if (menuEditing) {
    display.fillRect(0, 0, OLED_W, 9, SSD1306_WHITE);
    display.setTextColor(SSD1306_BLACK);
  } else {
    display.setTextColor(SSD1306_WHITE);
  }
  display.setCursor(0, 0);
  printClipped(header);
  display.setTextColor(SSD1306_WHITE);
}

void drawMenu() {
  if (!oledOK) return;

  display.clearDisplay();
  drawMenuHeader();
  drawCenteredText(menuValue(), 11, 2);
  drawCenteredText(menuDetail(), 25, 1);
  display.display();
}

// ============================================================
//  SYNTH ENGINE  (polyphonic, multi-family)
// ============================================================
const int     SR         = 20000;
const int     MAX_LEN    = 600;
const int     MAX_VOICES = 10;
const uint8_t DC_MID     = 128;

// Sine lookup table (power-of-two length for cheap phase masking).
const int   SINE_N = 256;
float       sineTab[SINE_N];

inline float sineLookup(float cycles) {
  // cycles >= 0; masking handles values >= 1.0 (harmonics).
  int idx = (int)(cycles * SINE_N) & (SINE_N - 1);
  return sineTab[idx];
}

// Shared low-frequency oscillator for flute vibrato.
const float VIB_RATE  = 5.0f;          // Hz
const float VIB_DEPTH = 0.004f;        // +/- pitch modulation (~7 cents)
const float VIB_INC   = VIB_RATE / SR;
float       vibratoPhase = 0.0f;

// Fast noise for percussion (xorshift; avoids per-sample random()).
uint32_t rngState = 0x9E3779B9u;
inline float fastNoise() {
  rngState ^= rngState << 13;
  rngState ^= rngState >> 17;
  rngState ^= rngState << 5;
  return (int32_t)rngState * (1.0f / 2147483648.0f);  // ~ -1..1
}

struct Voice {
  bool      active;
  VoiceKind kind;
  int       pad;        // owning pad for sustained note-off, -1 if none
  // Karplus buffer (pluck)
  float     buf[MAX_LEN];
  int       len, idx;
  float     decay;
  uint32_t  life;
  // Oscillator (tone / perc)
  float     phase;      // cycles [0,1)
  float     phaseInc;   // cycles per sample
  float     env;        // amplitude envelope
  float     env2;       // perc noise-transient envelope
  bool      sustaining; // tone: pad still held
  float     attackRate, releaseRate;
};
Voice voices[MAX_VOICES];
int   nextVoice = 0;
int   padVoice[NUM];    // sustained voice index per pad, -1 = none

void smoothBuffer(float *b, int len, int passes) {
  for (int p = 0; p < passes; p++) {
    float prev = b[len - 1];
    for (int i = 0; i < len; i++) {
      float cur = b[i];
      int n = i + 1;
      if (n >= len) n = 0;
      float nv = (prev + 2.0f * cur + b[n]) * 0.25f;
      prev = cur;
      b[i] = nv;
    }
  }
}

// Pick a free voice, or steal the round-robin one. Clears any pad ownership.
int allocVoice() {
  int v = -1;
  for (int i = 0; i < MAX_VOICES; i++) {
    if (!voices[i].active) { v = i; break; }
  }
  if (v < 0) {
    v = nextVoice;
    nextVoice = (nextVoice + 1) % MAX_VOICES;
  }
  Voice &vc = voices[v];
  if (vc.pad >= 0 && vc.pad < NUM && padVoice[vc.pad] == v) padVoice[vc.pad] = -1;
  vc.pad = -1;
  return v;
}

void startPluck(float freq, float decay = 0.9968f, int smoothPasses = 5, float lifeSec = 3.2f) {
  if (freq <= 0) return;
  int v = allocVoice();
  Voice &vc = voices[v];
  vc.kind = VK_PLUCK;
  vc.len = SR / freq;
  if (vc.len > MAX_LEN) vc.len = MAX_LEN;
  if (vc.len < 2) vc.len = 2;
  for (int i = 0; i < vc.len; i++) {
    vc.buf[i] = (random(0, 2001) / 1000.0f) - 1.0f;
  }
  smoothBuffer(vc.buf, vc.len, smoothPasses);
  vc.idx = 0;
  vc.decay = decay;
  vc.life = (uint32_t)(SR * lifeSec);
  vc.active = true;
}

// Start a sustained voice (Keyboard tone or Flute) owned by a pad.
void startTone(VoiceKind kind, float freq, float attackSec, float releaseSec, int pad) {
  if (freq <= 0) return;
  int v = allocVoice();
  Voice &vc = voices[v];
  vc.kind = kind;
  vc.phase = 0.0f;
  vc.phaseInc = freq / SR;
  vc.env = 0.0f;
  vc.attackRate  = 1.0f / (attackSec  * SR);
  vc.releaseRate = 1.0f / (releaseSec * SR);
  vc.sustaining = true;
  vc.pad = pad;
  vc.life = 0;
  vc.active = true;
  if (pad >= 0 && pad < NUM) padVoice[pad] = v;
}

void startPerc(float freq, float decaySec) {
  if (freq <= 0) return;
  int v = allocVoice();
  Voice &vc = voices[v];
  vc.kind = VK_PERC;
  vc.phase = 0.0f;
  vc.phaseInc = freq / SR;
  vc.env = 1.0f;
  vc.env2 = 1.0f;
  vc.releaseRate = 1.0f / (decaySec * SR);
  vc.pad = -1;
  vc.life = 0;
  vc.active = true;
}

// Trigger the current instrument on a pad press.
void playNote(int pad, float freq) {
  const Instrument &ins = INSTRUMENTS[instrumentIdx];
  switch (ins.kind) {
    case VK_PLUCK:
      startPluck(freq, ins.decay, ins.smoothPasses, ins.lifeSec);
      if (ins.harmonic) startPluck(freq * 2.0f, 0.9900f, 1, 0.35f);
      break;
    case VK_TONE:
    case VK_FLUTE:
      startTone(ins.kind, freq, ins.attackSec, ins.releaseSec, pad);
      break;
    case VK_PERC:
      startPerc(freq, ins.percDecaySec);
      break;
  }
}

// Release a sustained (Keyboard) note when the pad is let go. No-op otherwise.
void noteOff(int pad) {
  int v = padVoice[pad];
  if (v < 0) return;
  padVoice[pad] = -1;
  if (voices[v].active && isSustainedKind(voices[v].kind) && voices[v].pad == pad) {
    voices[v].sustaining = false;
  }
}

inline void deactivate(Voice &vc, int i) {
  vc.active = false;
  if (vc.pad >= 0 && vc.pad < NUM && padVoice[vc.pad] == i) padVoice[vc.pad] = -1;
}

inline float renderSample() {
  // Advance the shared vibrato LFO once per output sample.
  vibratoPhase += VIB_INC;
  if (vibratoPhase >= 1.0f) vibratoPhase -= 1.0f;
  float vibMod = 1.0f + VIB_DEPTH * sineLookup(vibratoPhase);

  float mix = 0.0f;
  for (int i = 0; i < MAX_VOICES; i++) {
    Voice &vc = voices[i];
    if (!vc.active) continue;

    float out = 0.0f;
    if (vc.kind == VK_PLUCK) {
      int n = vc.idx + 1;
      if (n >= vc.len) n = 0;
      out = vc.buf[vc.idx];
      vc.buf[vc.idx] = 0.5f * (vc.buf[vc.idx] + vc.buf[n]) * vc.decay;
      vc.idx = n;
      if (vc.life) vc.life--; else deactivate(vc, i);

    } else if (vc.kind == VK_TONE) {
      // Organ-ish additive tone: fundamental + octave + fifth-above.
      float s = sineLookup(vc.phase)
              + 0.45f * sineLookup(vc.phase * 2.0f)
              + 0.20f * sineLookup(vc.phase * 3.0f);
      s *= 0.5f;                       // headroom for the harmonic sum
      vc.phase += vc.phaseInc;
      if (vc.phase >= 1.0f) vc.phase -= 1.0f;
      if (vc.sustaining) {
        vc.env += vc.attackRate;
        if (vc.env > 1.0f) vc.env = 1.0f;
      } else {
        vc.env -= vc.releaseRate;
        if (vc.env <= 0.0f) { vc.env = 0.0f; deactivate(vc, i); }
      }
      out = s * vc.env;

    } else if (vc.kind == VK_FLUTE) {
      // Near-pure tone (fundamental + faint octave) + breath noise + vibrato.
      float s = sineLookup(vc.phase) + 0.12f * sineLookup(vc.phase * 2.0f);
      s = s * 0.85f + fastNoise() * 0.05f;
      vc.phase += vc.phaseInc * vibMod;
      if (vc.phase >= 1.0f) vc.phase -= 1.0f;
      if (vc.sustaining) {
        vc.env += vc.attackRate;
        if (vc.env > 1.0f) vc.env = 1.0f;
      } else {
        vc.env -= vc.releaseRate;
        if (vc.env <= 0.0f) { vc.env = 0.0f; deactivate(vc, i); }
      }
      out = s * vc.env;

    } else { // VK_PERC
      float body = sineLookup(vc.phase);
      vc.phase += vc.phaseInc;
      if (vc.phase >= 1.0f) vc.phase -= 1.0f;
      vc.phaseInc *= 0.99985f;         // pitch drops -> drum "thump"
      float noise = fastNoise();
      out = 0.6f * body * vc.env + 0.9f * noise * vc.env2;
      vc.env  -= vc.releaseRate;
      vc.env2 *= 0.9988f;              // noise transient decays fast
      if (vc.env <= 0.0f) { vc.env = 0.0f; deactivate(vc, i); }
    }

    mix += out;
  }
  return mix;
}

// ---- Render a small chunk of audio (paced to sample rate) ----
const int CHUNK = 32;          // 32 samples @ 20kHz ~= 1.6 ms between scans
uint32_t audioNext = 0;

inline int shapeSample(float v) {
  v *= 0.5f;
  if (v > 1.0f) v = 1.0f;
  else if (v < -1.0f) v = -1.0f;
  else v = 1.5f * v - 0.5f * v * v * v;   // soft clip
  int d = (int)(v * 120.0f) + DC_MID;
  if (d < 0) d = 0;
  if (d > 255) d = 255;
  return d;
}

void renderChunk() {
  uint32_t periodUs = 1000000UL / SR;
  for (int i = 0; i < CHUNK; i++) {
    dacWrite(DAC_PIN, shapeSample(renderSample()));
    audioNext += periodUs;
    while ((int32_t)(micros() - audioNext) < 0) { }
  }
  if ((int32_t)(micros() - audioNext) > 2000) audioNext = micros();
}

// ============================================================
//  INPUT STATE
// ============================================================
bool     touchHeld[NUM];    // capacitive state after hysteresis
bool     padHeld[NUM];      // selected input mode held state
uint32_t lastTrig[NUM];     // last trigger time (for cooldown)

bool     btnWas[2]  = { false, false };
uint32_t btnLast[2] = { 0, 0 };

int      encLastClk = HIGH;
bool     encSwWas   = false;
uint32_t encSwLast  = 0;

void resetPadStates() {
  for (int i = 0; i < NUM; i++) {
    touchHeld[i] = false;
    padHeld[i] = false;
    // release any sustained notes owned by pads when the mode changes
    if (padVoice[i] >= 0) { noteOff(i); }
    padVoice[i] = -1;
  }
  lastDigitalActiveMask = 0xFF;
  ledsDirty = true;
}

void configurePadInputs() {
  for (int i = 0; i < NUM; i++) {
    if (playMode == MODE_DIGITAL && DIGITAL_INPUT_PULLDOWNS) {
      pinMode(PAD_PIN[i], INPUT_PULLDOWN);
    } else {
      pinMode(PAD_PIN[i], INPUT);
    }
  }
}

bool readDigitalPad(int i) {
  if (playMode != MODE_DIGITAL) return false;
  pinMode(PAD_PIN[i], DIGITAL_INPUT_PULLDOWNS ? INPUT_PULLDOWN : INPUT);
  int level = digitalRead(PAD_PIN[i]);
  return DIGITAL_INPUT_ACTIVE_LOW ? (level == LOW) : (level == HIGH);
}

void logDigitalActiveMask(uint8_t mask) {
  if (mask == lastDigitalActiveMask) return;
  lastDigitalActiveMask = mask;

  Serial.print("digital GPIO active: ");
  if (mask == 0) {
    Serial.println("none");
    return;
  }
  for (int i = 0; i < NUM; i++) {
    if (mask & (1 << i)) {
      Serial.printf("pad%d(GPIO%d) ", i + 1, PAD_PIN[i]);
    }
  }
  Serial.println();
}
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
void loop() {
  renderChunk();    // ~1.6 ms of audio
  scanKeys();       // trigger notes in Capacitive or Digital mode
  scanButtons();    // optional scale up/down buttons
  scanEncoder();    // OLED menu navigation/editing
  updateScaleButtonMessage();
  updateLeds();     // show active pads and decay trigger flashes
}

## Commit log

2026-07-01 project init
    [music-kit.kicad_pcb, music-kit.kicad_sch]
2026-07-11 pcb finished
    [music-kit.kicad_pcb, music-kit.kicad_sch]
2026-07-21 add landing
